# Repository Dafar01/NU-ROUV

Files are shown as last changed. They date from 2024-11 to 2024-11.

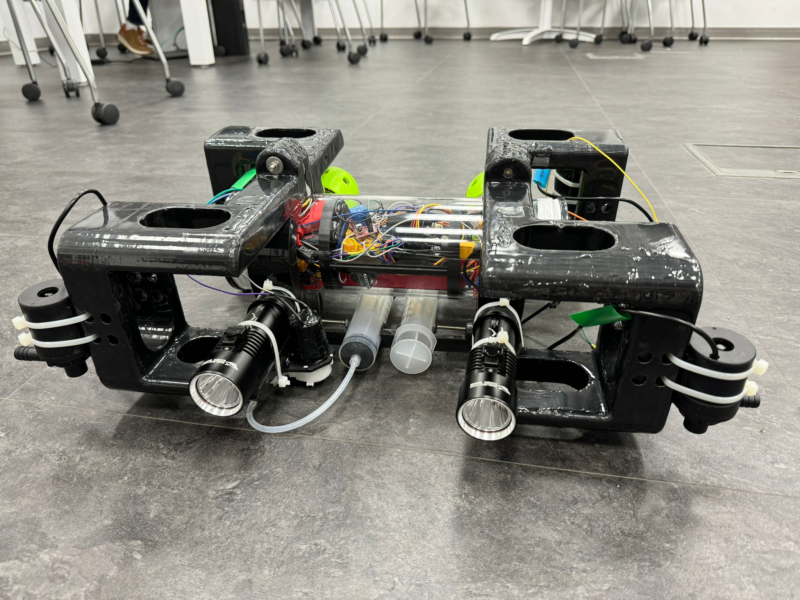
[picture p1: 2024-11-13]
Images/Submarine Front.jpg

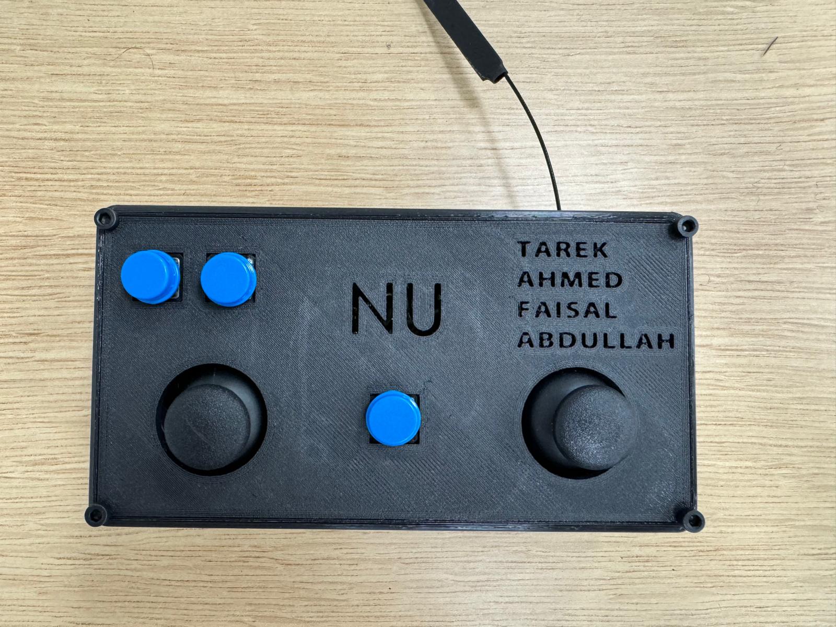
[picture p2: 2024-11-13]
Images/Controller Top1.jpg

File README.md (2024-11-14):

# NU ROUV

For reference, ROUV stands for **"Remotely Operated Underwater Vehicle"**
<p align="center">
   
</p>

This GitHub repo is for the to be published paper *NU - A Marine Life Monitoring and Exploration Submarine*. This milestone was also our capstone/graduation project at the American University of Kuwait (AUK).

# Description
NU is a marine life monitoring ROUV/submarine that is equipped with a machine learning pipeline capable of identifying and classifying 5 fish species in kuwait seas, while simultaneously flagging any species outside of the dataset as unknowns. NU also aims to cut down costs on ocean exploration expeditions, reduce disturbance and damage on marine life, and limit health risks imposed on divers due to diving.

## Key Features
- **Wireless Communication**: NU utilizes LoRa as its main communication technology, allowing it to be operated wirelessly in real-time using a controller without the need for a teather.
- **Machine Learning Pipeline**: NU is equipeed with a camera that transmits a live-feed to a laptop. The footage is then analyzed in real-time and the results are displayed on screen.
- **Two Modes of Transportation**: NU has two sets of motors, Brushless DC motors and water pump motors. The Brushless DC motors are used for long distance travelling, while the water pumps are used for precise movement and limiting disturbance on marine life.
- **Eco-friendly 3D Parts**: NU's body is fully 3D printed using biodegradable materials, eliminating the risk of pollution in case the submarine is lost during operation.

## Hardware

### Electrical Components
Below is a list of all the electrical components needed to implement NU:
- **Arduino UNO R3**
- **LoRa SX1278 433Mhz Module** (depends on your region)
- **11.1V 6000mAh Li-Po Battery**
- **Two 12V Brushless DC Waterproofed Motors**
- **Two 45A ESCs**
- **Four Water Pump Motors**
- **Two Peristaltic Pump Motors**
- **60 FPS 1080p Bullet Camera**
- **Two 4-channel 12V Relay Modules**
- **Infrared Relay**
- **Fuse**
- **Scuba Diving Flashlights**

### Circuits
#### Controller Circuit
Controller Circuit

#### Submarine Circuit
Submarine Circuit

### 3D Designs
All the 3D STL files are available in the [STL Files](/STL_Files) folder.

#### Disclaimers
- For symmetry, 4 of the [Acrylic Tube Holder](/3D_Designs/Acrylic_Tube_Holder.STL) were printed. The acrylic tube used was roughly 30cms long and 10cms in diameter.
- A waterproof wire-gland is used with the [End Cap](/3D_Designs/End_Cap.STL) to pass the motor wires from inside the acrylic tube to the outside, hence the opening in the middle.
- The pillars designed in [the bottom part of the controller](/3D_Designs/Controller_Bottom.STL) are weak. Consider adding a fillet between the bottom of the case and the pillars, and between the top pillars and bottom pillars.

## Software
The software implementation of both circuits and the machine learning pipeline are avaialble in the [Code](/Code) folder.

## Demo
Demo videos of the motors operating as well as a montage of the NU's functionalities is available in the [Video](/Video) folder.

## License
This project is licensed under the MIT License - see the [LICENSE](LICENSE) file for details.

## Authors
- Tarek Dafar
- Ahmed Hassan
- Faisal Hassan
- Abdullah AlGohary

## Supervisors
- Dr. Mounib Khanafer
- Eng. Ali Behiry

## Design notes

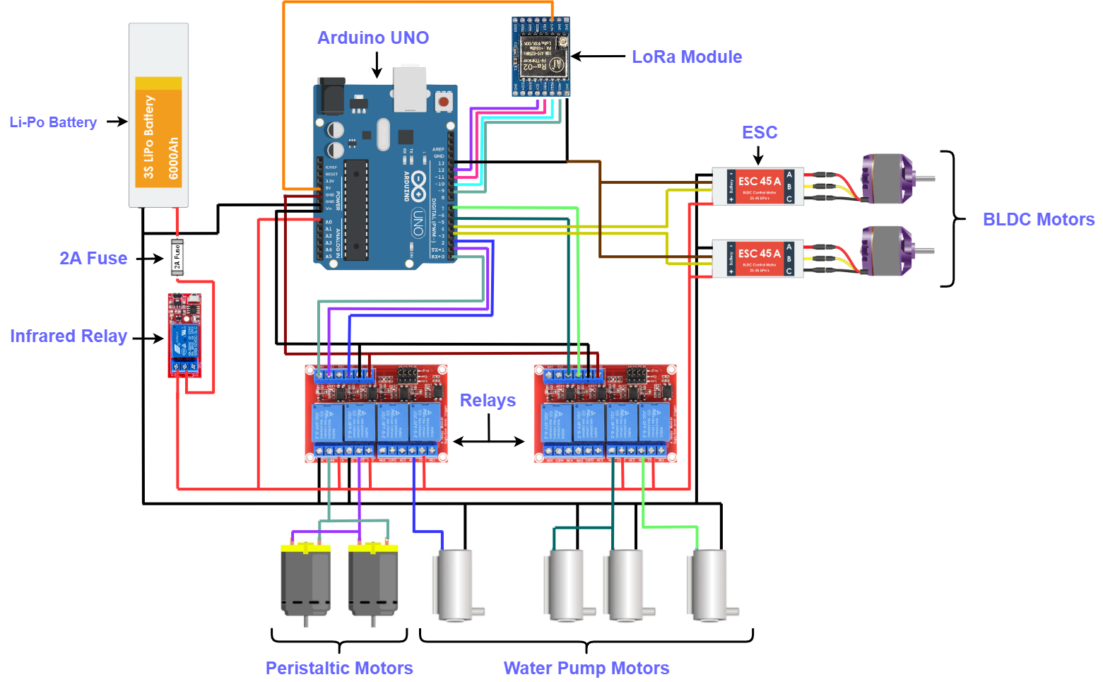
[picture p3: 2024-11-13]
Images/Submarine Circuit.png

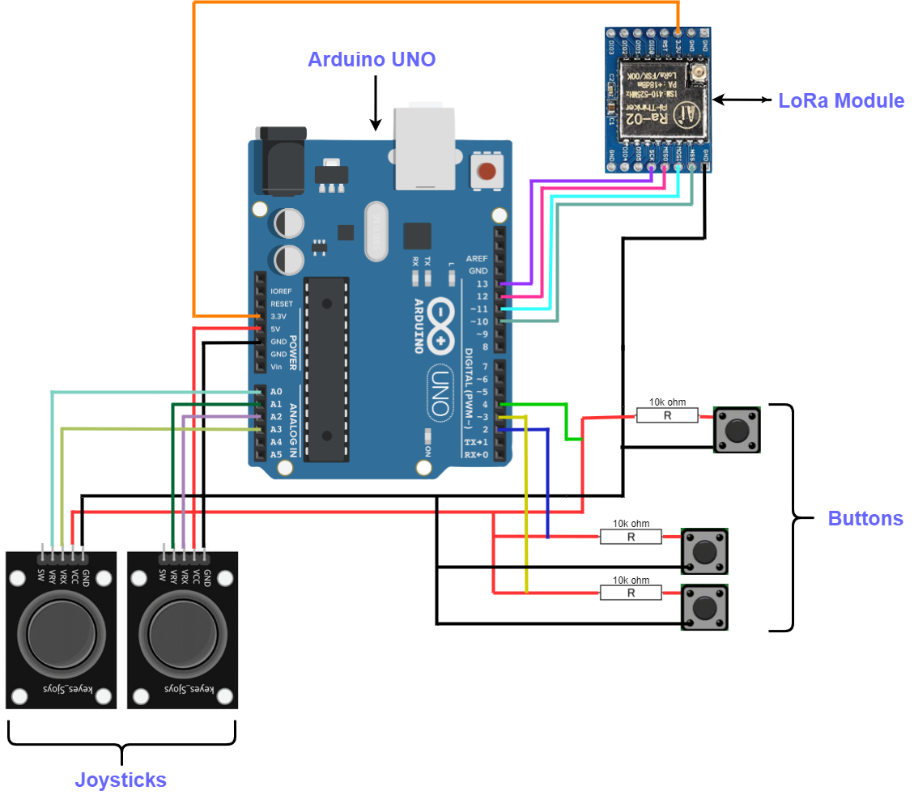
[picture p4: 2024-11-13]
Images/Controller Circuit.png

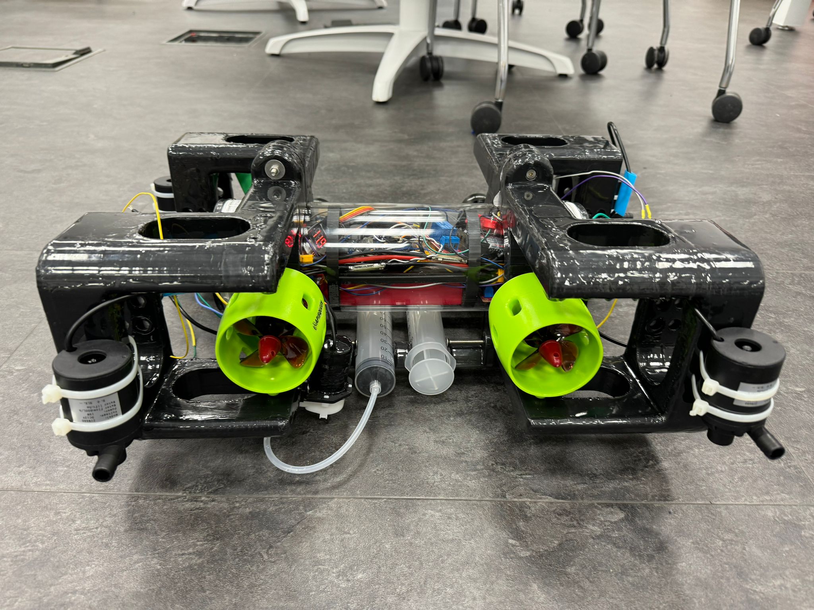
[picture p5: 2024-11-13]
Images/Submarine Back.jpg

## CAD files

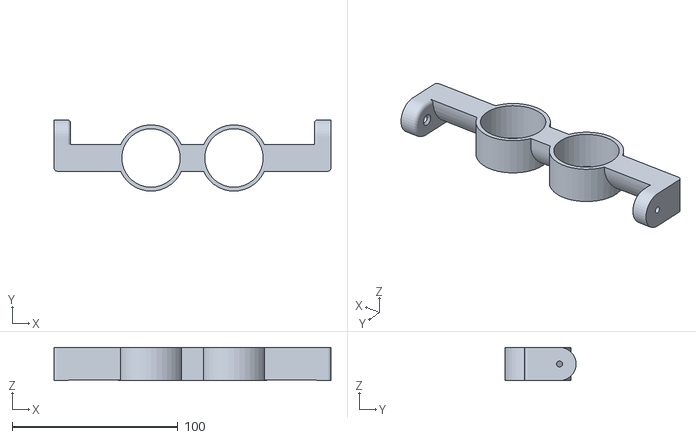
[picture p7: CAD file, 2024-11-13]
STL_Files/Syringe_Holder.STL
167.0 x 43.0 x 20.0

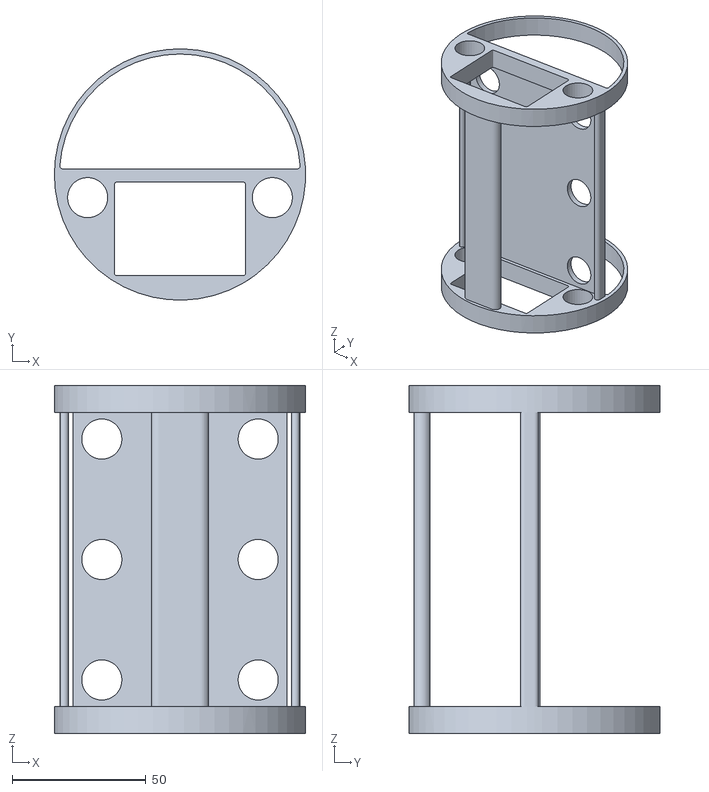
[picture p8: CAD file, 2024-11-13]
STL_Files/Component_Holder.STL
93.9 x 93.8 x 130.0

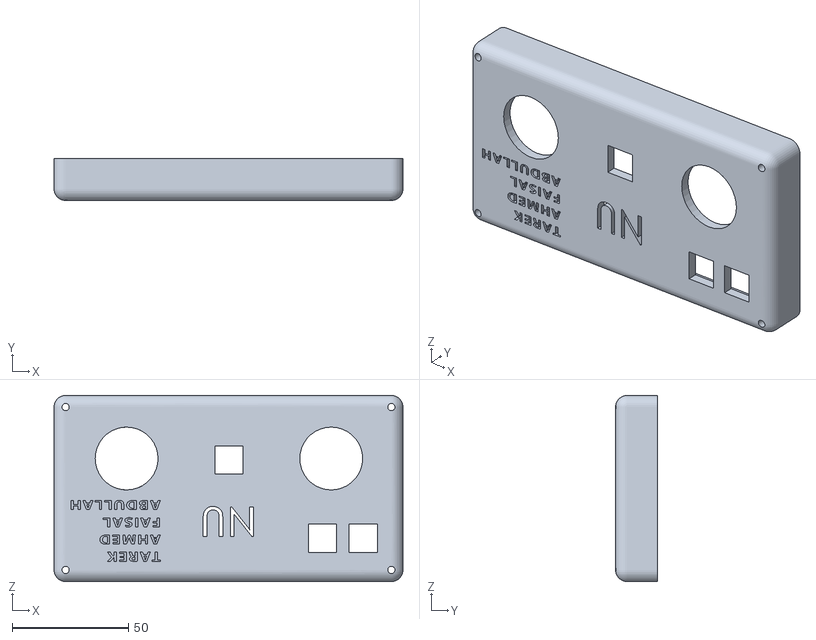
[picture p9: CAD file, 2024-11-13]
STL_Files/Controller_Top.STL
150.0 x 18.0 x 80.0

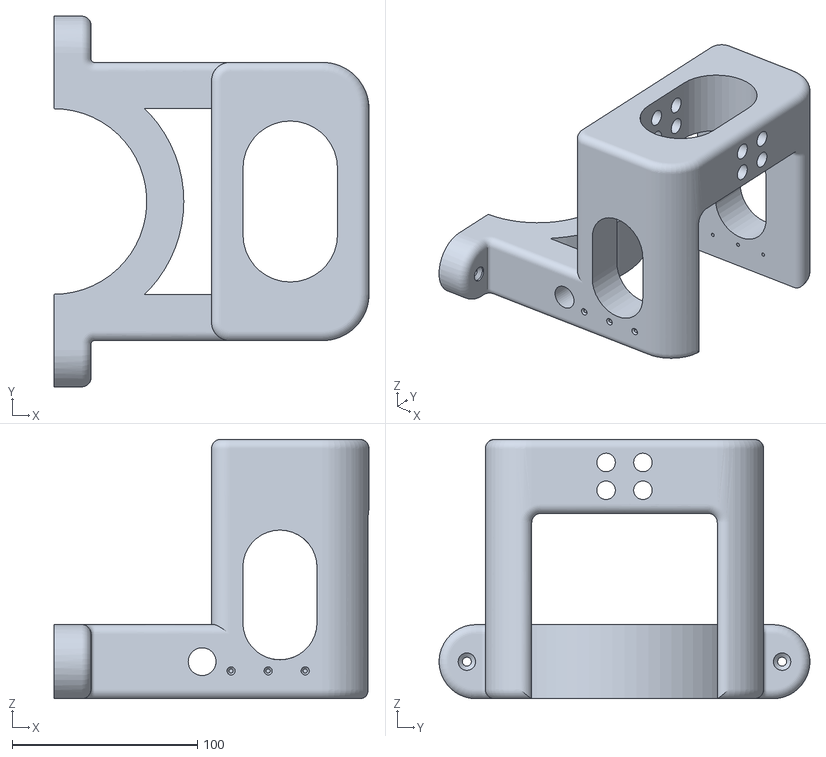
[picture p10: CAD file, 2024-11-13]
STL_Files/Acrylic_Tube_Holder.STL
170.0 x 200.1 x 140.0

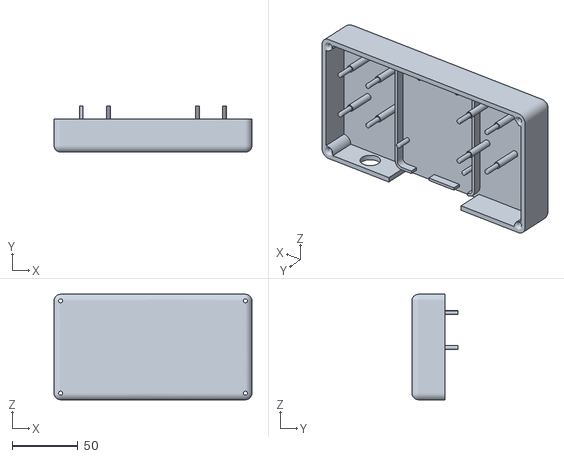
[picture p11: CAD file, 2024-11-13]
STL_Files/Controller_Bottom.STL
150.0 x 35.0 x 80.0

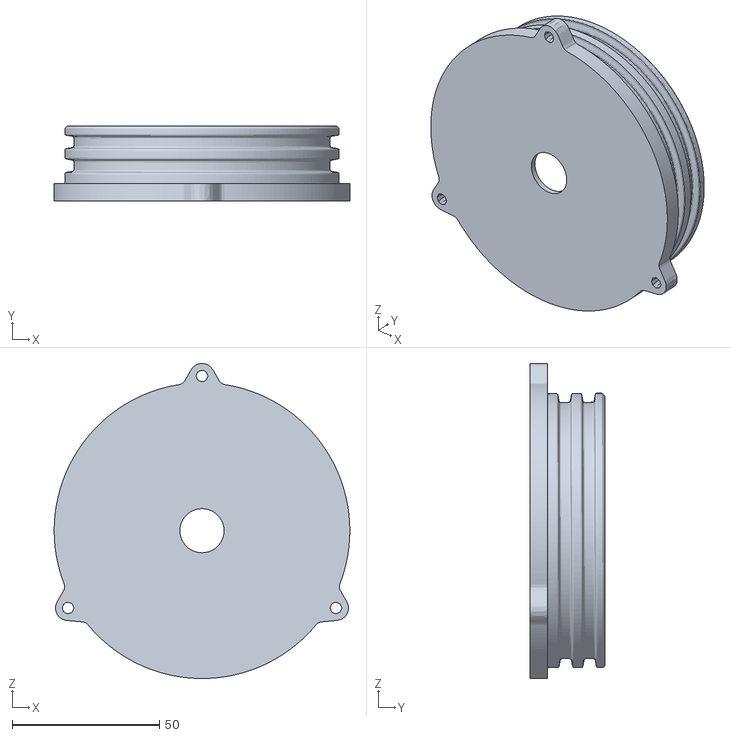
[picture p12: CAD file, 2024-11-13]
STL_Files/End_Cap.STL
100.4 x 25.4 x 107.0

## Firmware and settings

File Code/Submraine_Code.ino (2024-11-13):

#include <SPI.h>
#include <Wire.h>
#include <LoRa.h>
#include <Servo.h>

Servo escFor1;
Servo escFor2;

#define ESC_PIN 5
#define ESC_PIN1 6
#define PumpFor 7
#define PumpLeft 8
#define PumpRight 4
#define sinkPin 2
#define surfacePin 3

// Define variables for controlling relay timings
unsigned long pumpActivationTime = 0;
const unsigned long pumpActivationDuration = 1000; // Adjust as needed
unsigned long previousMillis = 0; // Variable to store the last time the syringe action was performed
const long interval = 3000;       // Interval between syringe actions (in milliseconds)

int checking = -1;
int joyValy1, joyValy2, joyValx1, joyValx2, sink, surface;

void setup() {
  Serial.begin(9600);

  escFor1.attach(ESC_PIN, 1000, 2000);
  escFor1.write(0);
  delay(2000);
  escFor2.attach(ESC_PIN1, 1000, 2000);
  escFor2.write(0);
  delay(2000);

  pinMode(PumpFor, OUTPUT);
  pinMode(PumpLeft, OUTPUT);
  pinMode(PumpRight, OUTPUT);
  pinMode(sinkPin, OUTPUT);
  pinMode(surfacePin, OUTPUT);

  while (!Serial);
  Serial.println("LoRa Receiver");
  if (!LoRa.begin(433E6)) { // or 915E6
    Serial.println("Starting LoRa failed!");
    while (1);
  }

  delay(3000);
}

void loop() {
  Serial.println("back to loop");
  if (LoRa.parsePacket()) {
    while (LoRa.available()) {
      checking = LoRa.read();
      joyValy1 = LoRa.read();
      joyValy2 = LoRa.read();
      joyValx1 = LoRa.read();
      joyValx2 = LoRa.read();
      sink     = LoRa.read();
      surface  = LoRa.read();

      if (checking == 1) { // Mode for controlling BLDC motors
        controlBLDCMotors();
        Serial.println("going to BLDC");
      } else { // Mode for controlling water pumps
        controlWaterPumps();
        Serial.println("going to pumps");
        // controlSyringes();
      }
    }
  }
}

void controlBLDCMotors() {
  Serial.println("Controlling BLDC motors...");
  escFor1.write(joyValy1); // Control BLDC motor 1 with joystick Y1 value
  escFor2.write(joyValy2); // Control BLDC motor 2 with joystick Y2 value
  
  // Turn off water pumps
  digitalWrite(PumpFor, LOW);
  digitalWrite(PumpLeft, LOW);
  digitalWrite(PumpRight, LOW);
}

void controlWaterPumps() {
  Serial.println("Controlling water pumps...");

  // Turn off BLDC motors
  escFor1.write(90);
  escFor2.write(90);

  unsigned long currentMillis = millis();

  // Control water pumps
  if (joyValx1 < 80) {
    if (currentMillis - pumpActivationTime >= pumpActivationDuration) {
      digitalWrite(PumpFor, HIGH);
      pumpActivationTime = currentMillis;
      Serial.println("Forward engaged");
    }
  } else {
    digitalWrite(PumpFor, LOW);
  }

  if (joyValx2 < 80) {
    if (currentMillis - pumpActivationTime >= pumpActivationDuration) {
      digitalWrite(PumpRight, HIGH);
      pumpActivationTime = currentMillis;
      Serial.println("Right engaged");
    }
  } else {
    digitalWrite(PumpRight, LOW);
  }

  if (joyValx2 > 100) {
    if (currentMillis - pumpActivationTime >= pumpActivationDuration) {
      digitalWrite(PumpLeft, HIGH);
      pumpActivationTime = currentMillis;
      Serial.println("Left engaged");
    }
  } else {
    digitalWrite(PumpLeft, LOW);
  }

//-------------------------------------------

  if (sink == 0) {
    digitalWrite(surfacePin, LOW);
    digitalWrite(sinkPin, HIGH);
    Serial.println("sinking");

    // Check if it's time to turn off the sink
    if (currentMillis - previousMillis >= interval) {
      digitalWrite(sinkPin, LOW); // Turn off the sink
      Serial.println("sinking Turned off");
      previousMillis = currentMillis; // Save the current time for the next iteration
    }
  } else if (surface == 0) {
    digitalWrite(sinkPin, LOW);
    digitalWrite(surfacePin, HIGH);
    Serial.println("surface");

    // Check if it's time to turn off the surface
    if (currentMillis - previousMillis >= interval) {
      digitalWrite(surfacePin, LOW); // Turn off the surface
      Serial.println("surface Turned off");
      previousMillis = currentMillis; // Save the current time for the next iteration
    }
  } else {
    Serial.println("surface and sink off");
    digitalWrite(surfacePin, LOW);
    digitalWrite(sinkPin, LOW);
  }
}

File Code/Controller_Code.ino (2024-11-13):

#include <SPI.h>
#include <Wire.h>  // include libraries
#include <LoRa.h>

int joy1 = A0;  // Initialize pins
int joy2 = A1;
int joy3 = A2;
int joy4 = A3;
int sink = 2;
int surface = 3;
int mode = 4;
int modeTMP = 0;  // Varirables to be transmitted
int joyVal1;
int joyVal2;
int joyVal3;
int joyVal4;
int sinkVal;
int surfaceVal;
int modeVal;
void setup() {
  Serial.begin(9600);  // initialize serial
  pinMode(sink, INPUT);
  pinMode(surface, INPUT);
  pinMode(mode, INPUT);  // setup pins modes

  if (!LoRa.begin(433E6)) {
    Serial.println("LoRa init failed. Check your connections.");
    while (true)
      ;
    // if failed, do nothing
  }
  Serial.println("LoRa init succeeded.");
}
void loop() {

  joyVal1 = analogRead(joy1);  // read values from joysticks
  joyVal2 = analogRead(joy2);
  joyVal3 = analogRead(joy3);
  joyVal4 = analogRead(joy4);
  sinkVal = digitalRead(sink);  // read values from buttons
  surfaceVal = digitalRead(surface);
  modeVal = digitalRead(mode);
  Serial.println(modeVal);
  if (modeVal == LOW) {
    delay(70);  // debounce
    if (modeTMP == 0) {
      modeTMP = 1;

      Serial.println("SWITHED TO 1");
    } else if (modeTMP == 1) {
      modeTMP = 0;
      Serial.println("SWITHED TO 0");
    }
  }
  Serial.print("MODE: ");
  Serial.print(modeTMP);
  Serial.println();
  joyVal1 = map(joyVal1, 0, 1023, 0, 180);  // map values from 0-1023 to 0-180
  joyVal2 = map(joyVal2, 0, 1023, 0, 180);
  joyVal3 = map(joyVal3, 0, 1023, 0, 180);
  joyVal4 = map(joyVal4, 0, 1023, 0, 180);
  Serial.print("Vy value: ");
  Serial.print(joyVal1);
  Serial.print(" | Vy value: ");
  Serial.print(joyVal2);
  Serial.println();
  Serial.print("Vx value: ");
  Serial.print(joyVal3);
  Serial.print(" | Vx value: ");
  Serial.print(joyVal4);
  Serial.println();

  if (sinkVal == LOW) {
    Serial.print("Sinking: ");
    Serial.print(sinkVal);
    Serial.println();
  }
  if (surfaceVal == LOW) {
    Serial.print("Surfacing: ");
    Serial.print(surfaceVal);
    Serial.println();
  }
  LoRa.beginPacket();  // start packet
  LoRa.write(modeTMP);
  LoRa.write(joyVal1);  // add payload
  LoRa.write(joyVal2);
  LoRa.write(joyVal3);
  LoRa.write(joyVal4);
  LoRa.write(sinkVal);
  LoRa.write(surfaceVal);
  LoRa.endPacket();  // finish packet and send it
}

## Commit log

2024-11-13 Rename Submarine Printed Back.jpg to Submarine Back.jpg
2024-11-13 Rename Receiving Circuit.png to Submarine Circuit.png
2024-11-13 Rename Controller Top Printed.jpg to Controller Top.jpg
2024-11-13 Rename Fahad please forgive me 2.STL to End_Cap.STL
    [End_Cap.STL]
2024-11-13 Rename Left - Ring Assembly FINAL.STL to Acrylic_Tube_Holder.STL
    [Acrylic_Tube_Holder.STL]
2024-11-13 Rename My Controller - Bottom Platform.STL to Controller_Bottom.STL
    [Controller_Bottom.STL]
2024-11-13 Rename My Controller - Top Bigger Joysticks.STL to Controller_Top.STL
    [Controller_Top.STL]
2024-11-13 Rename NEW Component Holder.STL to Component_Holder.STL
    [Component_Holder.STL]
2024-11-13 Rename Syringe Holder.STL to Syringe_Holder.STL
    [Syringe_Holder.STL]
2024-11-13 Rename Controller Circuit.png to Controller Circuit1.png
2024-11-13 Controller Circuit.png
2024-11-13 Rename Submarine Circuit.png to Submarine Circuit1.png
2024-11-13 Submarine Circuit.png
